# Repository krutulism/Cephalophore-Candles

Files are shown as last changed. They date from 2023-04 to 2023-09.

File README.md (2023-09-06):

# Ladder-LEDs
KiCAD 7 files for a chainable PCB of individually addressable LEDs.

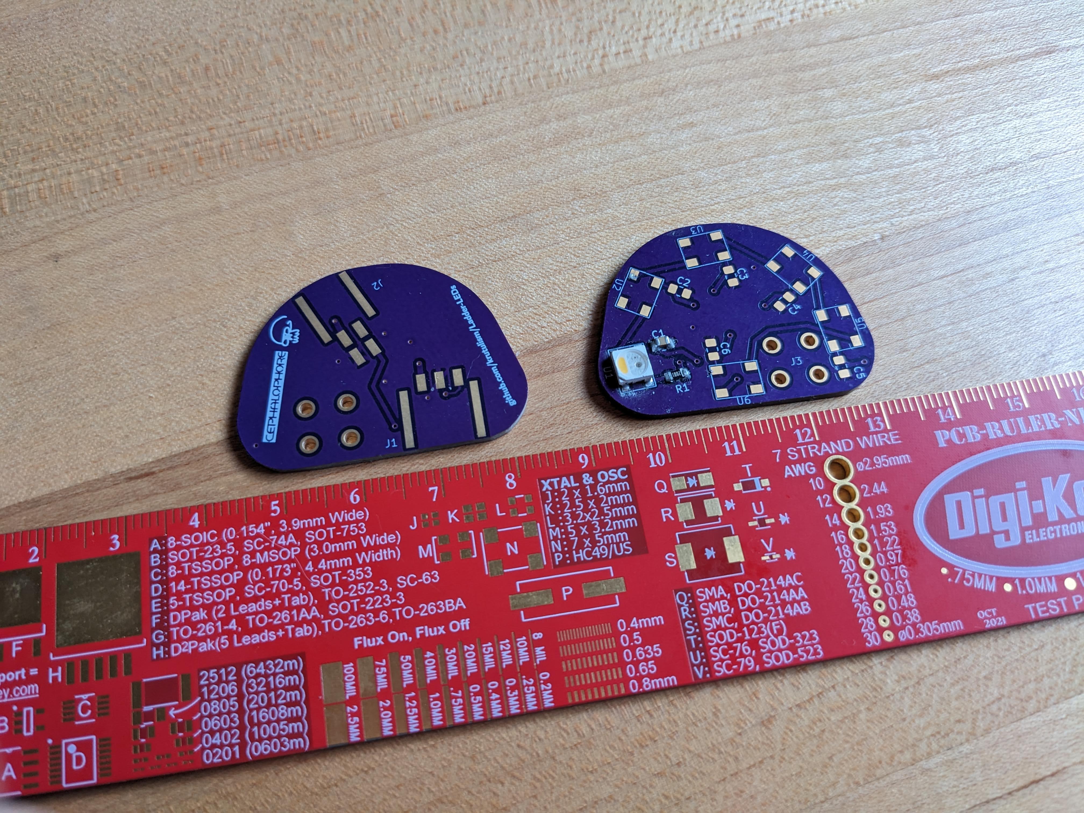
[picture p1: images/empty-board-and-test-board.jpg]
Empty board back and test board front

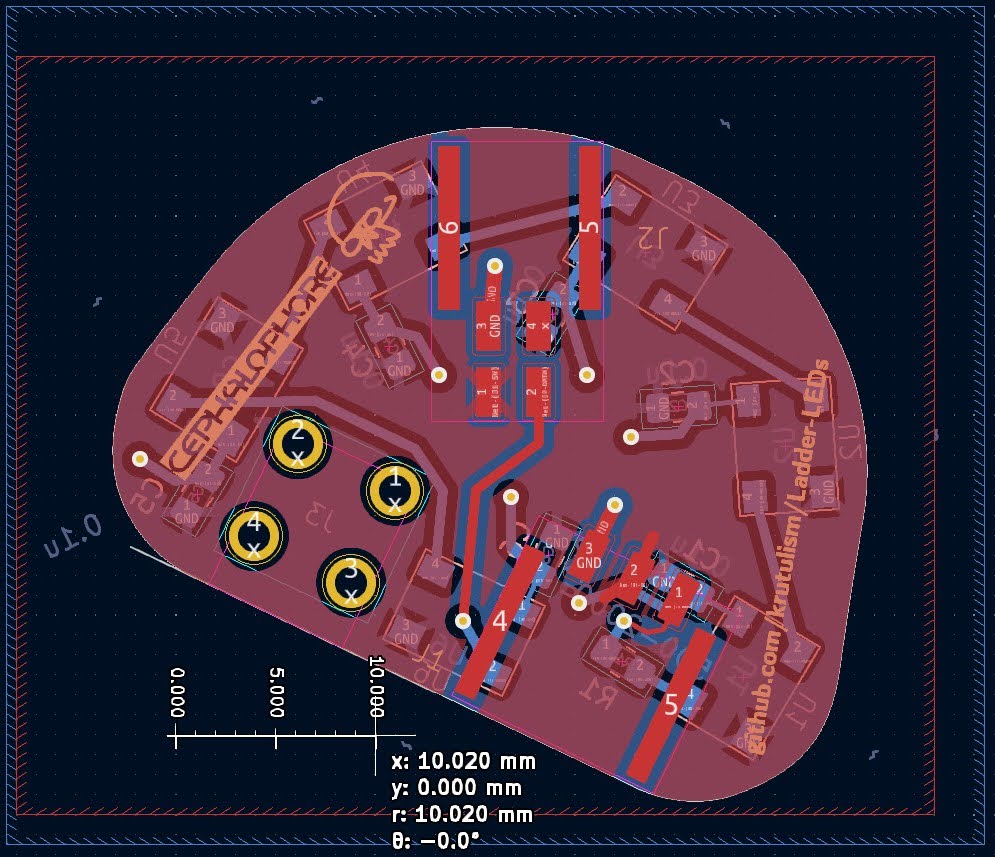
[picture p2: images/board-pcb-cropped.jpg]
PCB Layout from KiCAD


## Abstract
Strips of individually addressable LEDs are a popular and versatile gadget. Here I develop my own degree of craftsmanship beyond the adhesive strips they often come packaged on.

I used Molex connectors to chain together rigid fiberglass PCBs. The 'housing' that motivates the shape of the PCBs is the empty rungs of a salvaged aluminum extension ladder.

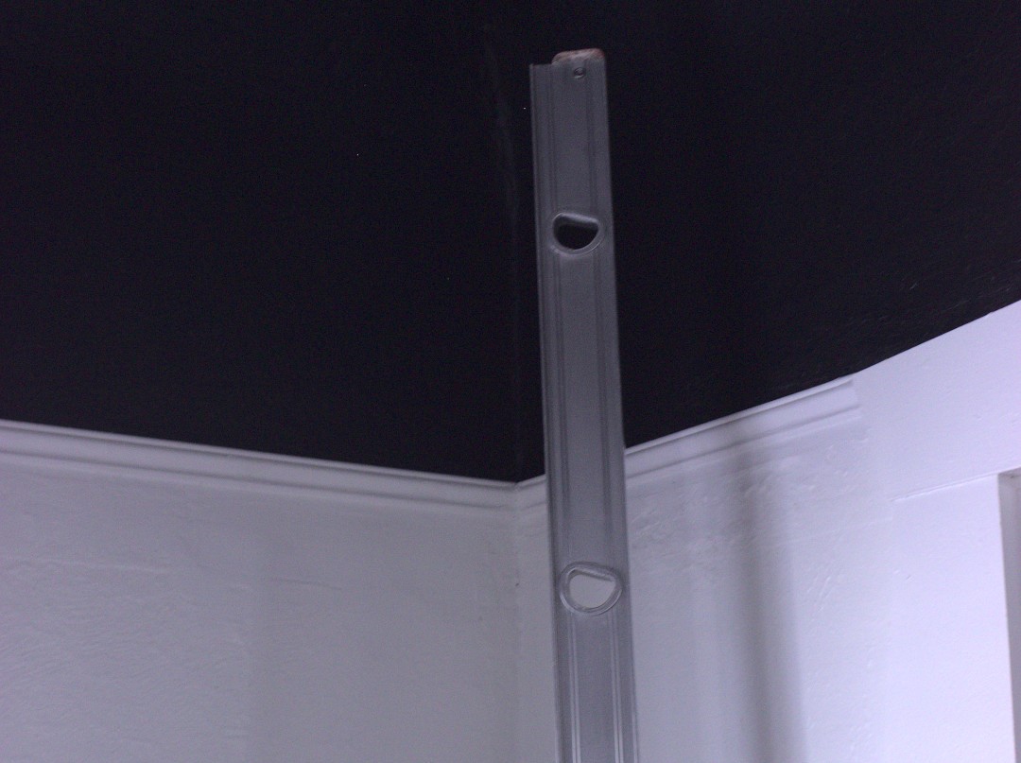
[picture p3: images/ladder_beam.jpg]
Scrapped aluminum ladder with D-shaped rungs


## Decision Tree
In each cut-off rung I will install a custom PCB designed in KiCAD.

The individually addressable LEDs I will use are the IN-PI55QATPRPGPBPW-40 RGBW shift register LEDs from Inolux.

The connector ecosystem that will allow me to chain these boards together are the Molex Nanofit system.

I will attempt to use a screw terminal block to mount the boards.

The prototype controller will be an Arduino Uno or Nano.

I will solder the surface mount components to the board by upgrading an IR reflow oven.

## First Demo
[Test program video (Google photos link)](https://photos.app.goo.gl/88sZqstjhHEQxjQ36)

## Instructions
To correct the paths to 3D models of custom library components: select a footprint in the PCB editor, edit its properties in the right click context menu or by pressing the E key, and enter the "3D Models" tab

CAD models I derived from datasheet drawings are included. CAD models I downloaded from the manufacturer can be downloaded from manufacturer websites.

## Questions
My Arduino firmware treats these LEDs as SK6812RGBW LEDs, a common hobbyist standard. However, here is a table of data transmission times for SK6812s accessed at Adafruit:
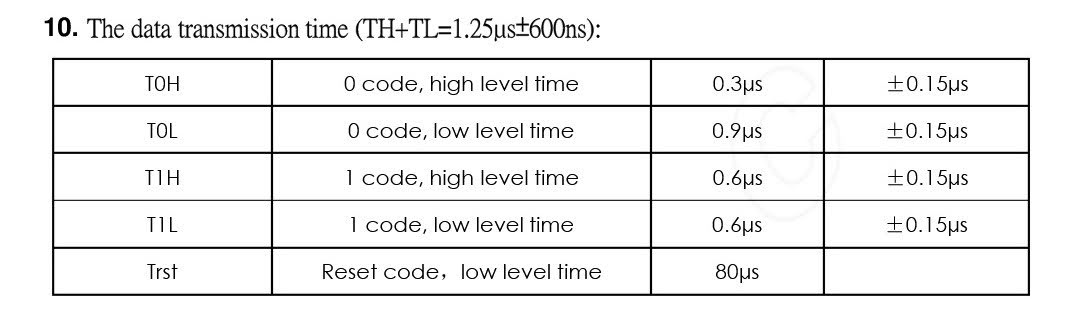
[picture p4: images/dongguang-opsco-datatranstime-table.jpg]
Data transmission times for SK6812


and here is the table for the Inolux IN-PI55QATPRPGPBPW-40 LEDs I used
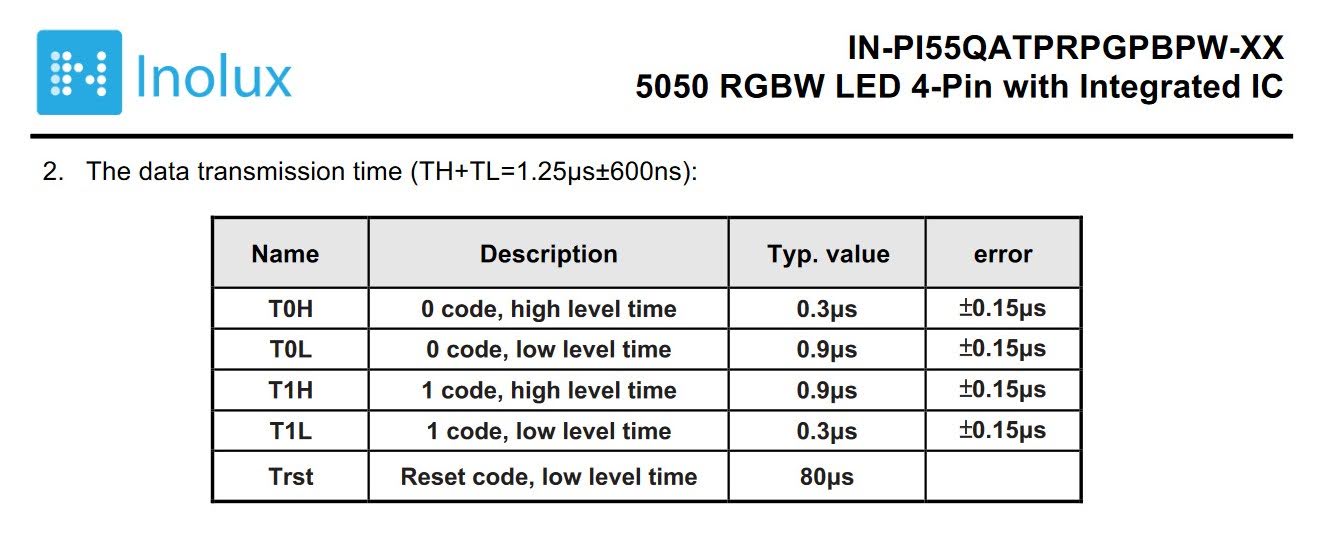
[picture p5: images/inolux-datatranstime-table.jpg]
Data transmission times for Inolux IN-PI...


In scrubbing through the source libraries for [Adafruit Neopixel](https://github.com/adafruit/Adafruit_NeoPixel), which is used in my demo, I did not find where these transmission times are encoded. This leaves me wondering where my elision will break down, whether after adding more LEDs to the chain, or under a greater frequency of intensity change commands. I will keep scrubbing the source code to understand, but suggestions are welcome.

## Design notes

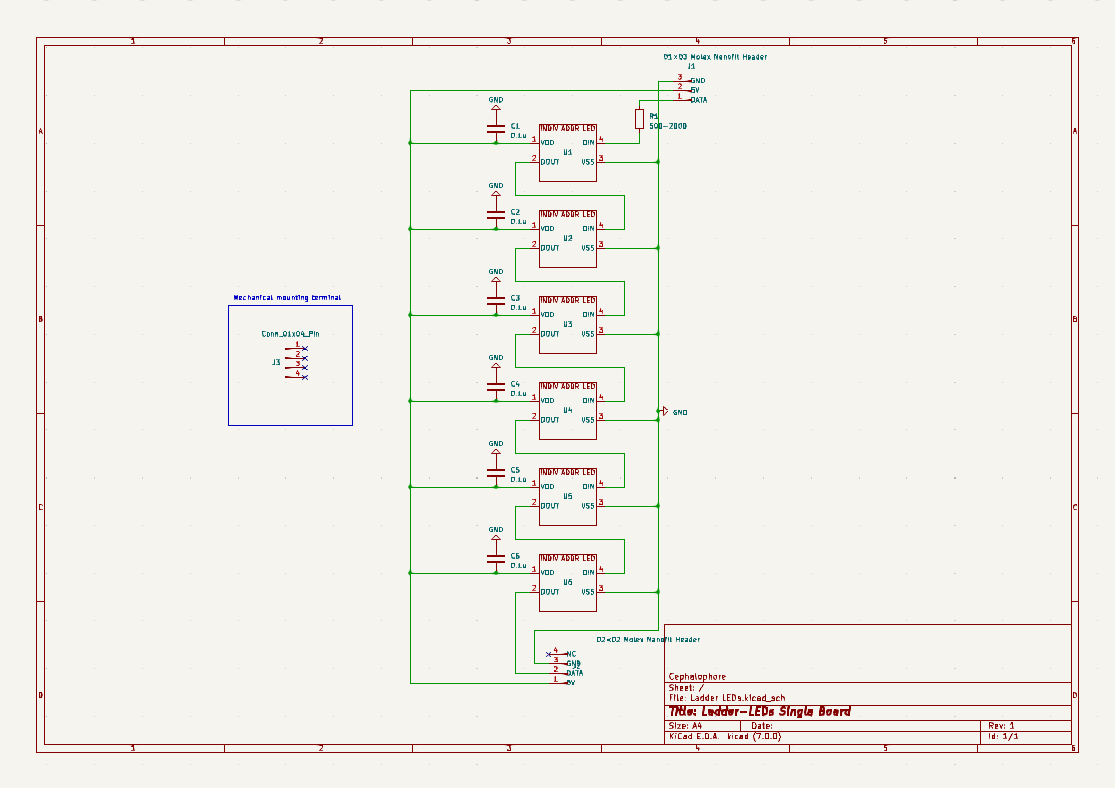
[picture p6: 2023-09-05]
images/KiCad_Schematic.png

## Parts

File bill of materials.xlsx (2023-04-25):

Index | Description |  | Color | Manufacturer | Manufacturer PN | Supplier | Approx price | Amount | URL
 | Nanofit receptacle 3-circuit | wire | Natural | Molex | 1053072203 (https://www.molex.com/molex/search/partSearch?query=1053072203&pQuery=) |  | $0.40 |  | https://www.digikey.com/en/products/detail/molex/1053072203/6164105?s=N4IgTCBcDaIIwAYCsBmBB2MYEpAXQF8g
 | Nanofit receptacle 4-circuit 2×2 | wire | Black | Molex | 1053081204 |  | $0.38 |  | https://www.digikey.com/en/products/detail/molex/1053081204/6131604?s=N4IgTCBcDaIIwAYCsBmBAOOYEBYQF0BfIA
 | Nanofit header 3-circuit |  |  | Molex | 1054302103 |  |  |  | https://www.digikey.com/en/products/detail/molex/1054302103/9959387?s=N4IgTCBcDaIIwAYCsAWAzAsi0gLoF8g
 | Nanofit header 4-circuit 2×2 |  |  | Molex | 1054051104 |  |  |  | https://www.newark.com/molex/105405-1104/conn-r-a-hdr-4pos-2row-2-5mm-smt/dp/26AK3878?st=1054051104
 | Nanofit terminals |  |  | Molex |  |  |  |  | https://www.molex.com/molex/search/partSearch?query=105300
 | Nanofit 3-position TPA retainer |  |  | Molex
 | Nanofit 2-position TPA retainer |  |  | Molex
 | Right angle 4-40 screw terminal | THT |  |  |  |  |  |  | https://www.digikey.com/en/products/detail/keystone-electronics/7773/4499350
 | Capacitor | SMD |  |  | 1276-1003-1-ND (https://www.digikey.com/en/products/detail/samsung-electro-mechanics/CL21B104KBCNNNC/3886661) |  |  |  | https://www.digikey.com/en/products/detail/samsung-electro-mechanics/CL21B104KBCNNNC/3886661
 | RGBW Indiv. Address. LED | SMD | Neutral white |  |  |  |  |  | https://www.digikey.com/en/products/detail/inolux/IN-PI55QATPRPGPBPW-40/9681240
 | Resistor
 | 4-40 screw

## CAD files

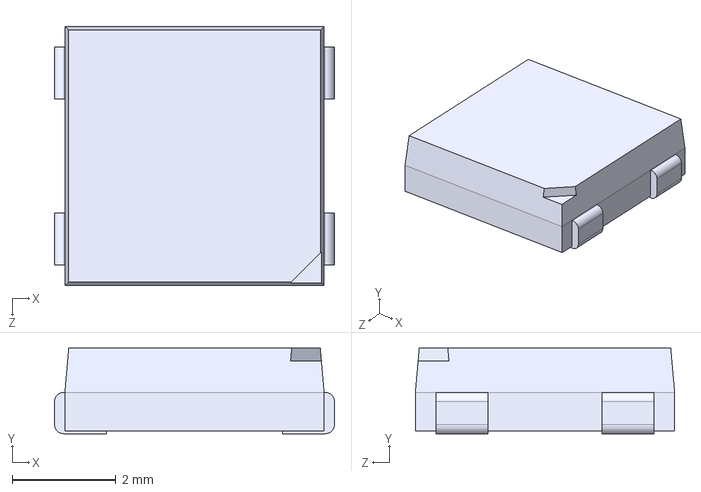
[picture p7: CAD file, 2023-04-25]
CAD models/IN-PI55QATPRPGPBPW-XX/IN-PI55QATPRPGPBPW-XX.STEP
5.40 x 1.65 x 5.00 mm

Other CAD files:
CAD models/IN-PI55QATPRPGPBPW-XX/IN-PI55QATPRPGPBPW-XX.SLDPRT

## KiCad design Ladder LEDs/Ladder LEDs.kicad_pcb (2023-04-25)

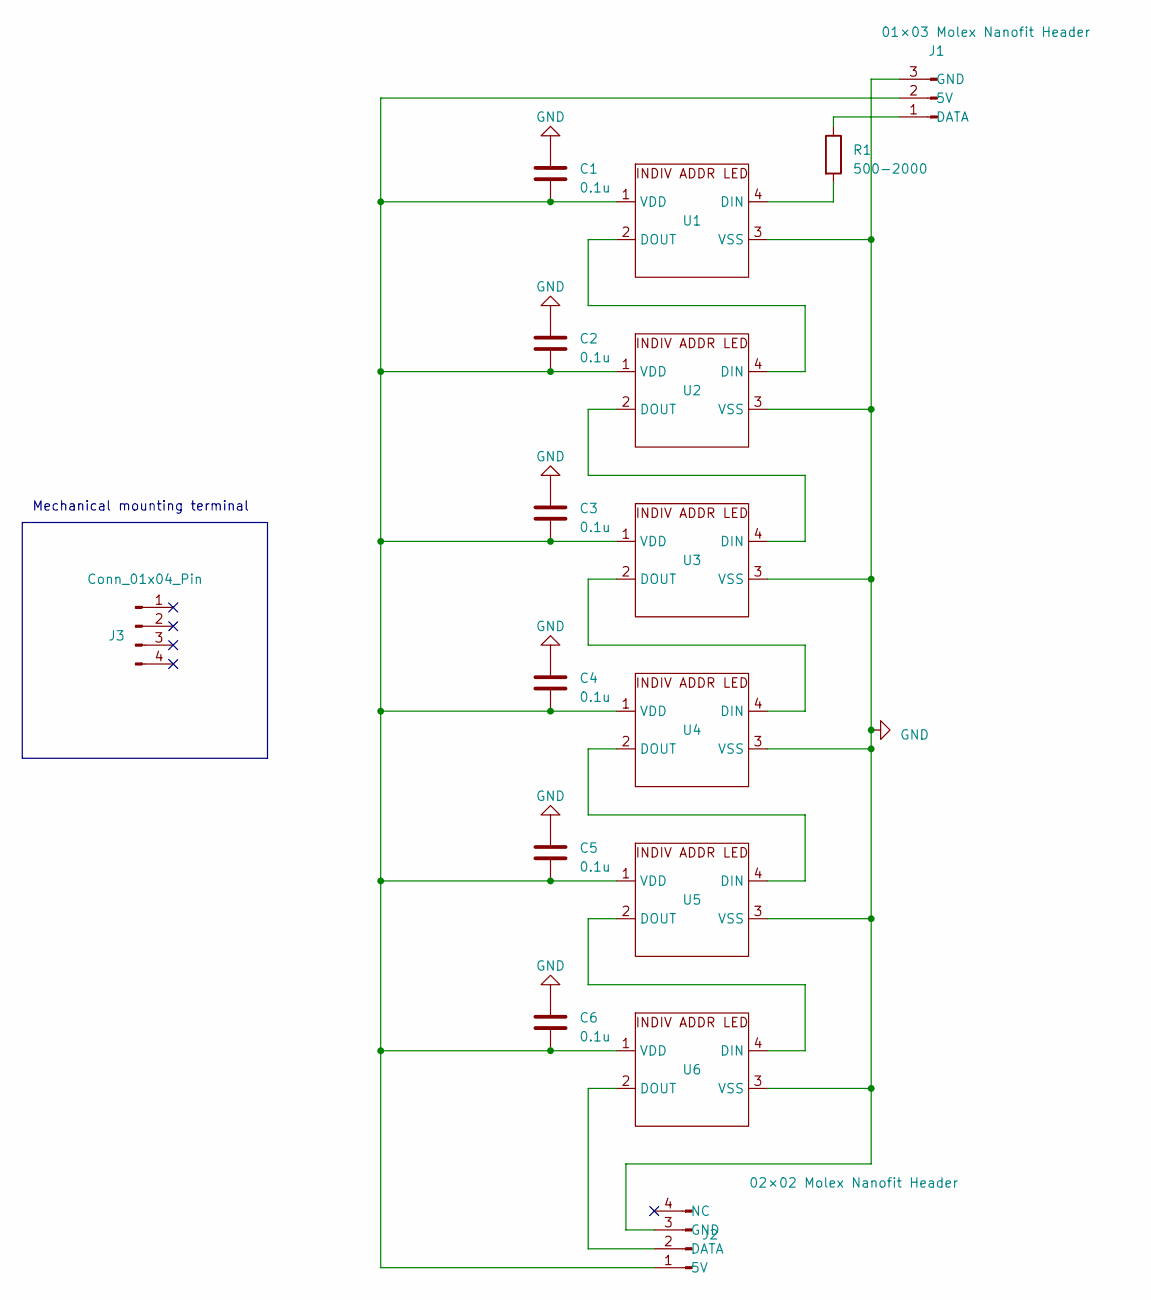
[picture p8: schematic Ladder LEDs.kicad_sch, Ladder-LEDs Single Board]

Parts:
C1, C2, C3, C4, C5, C6: 0.1u; C_0805_2012Metric_Pad1.18x1.45mm_HandSolder
J1: 01×03 Molex Nanofit Header; Molex 1054302103; MPN 1054302103
J2: 02×02 Molex Nanofit Header; Molex 105405-1104; MPN 1054051104
J3: Conn_01x04_Pin; 36-7773-ND; MPN 7773
R1: 500-2000; R_0805_2012Metric_Pad1.20x1.40mm_HandSolder
U1, U2, U3, U4, U5, U6: IN-PI55QATPRPGPBPW-XX

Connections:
GND: C1.1, C2.1, C3.1, C4.1, C5.1, C6.1, J1.3 (GND), J2.3 (GND), U1.3 (VSS), U2.3 (VSS), U3.3 (VSS), U4.3 (VSS), U5.3 (VSS), U6.3 (VSS)
unnamed: C1.2, C2.2, C3.2, C4.2, C5.2, C6.2, J1.2 (5V), J2.1 (5V), U1.1 (VDD), U2.1 (VDD), U3.1 (VDD), U4.1 (VDD), U5.1 (VDD), U6.1 (VDD)
unnamed: J1.1 (DATA), R1.1
unnamed: J2.2 (DATA), U6.2 (DOUT)
unnamed: R1.2, U1.4 (DIN)
unnamed: U1.2 (DOUT), U2.4 (DIN)
unnamed: U2.2 (DOUT), U3.4 (DIN)
unnamed: U3.2 (DOUT), U4.4 (DIN)
unnamed: U4.2 (DOUT), U5.4 (DIN)
unnamed: U5.2 (DOUT), U6.4 (DIN)

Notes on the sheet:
Mechanical mounting terminal

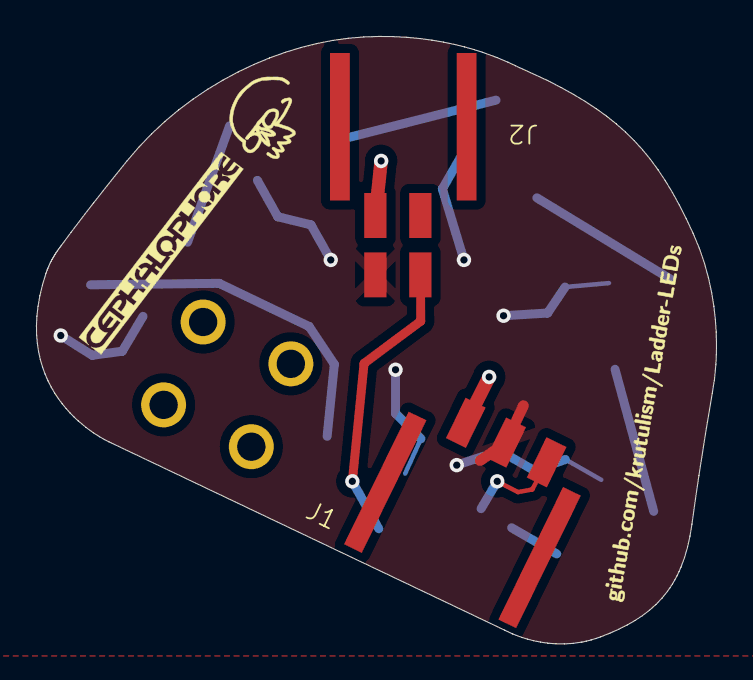
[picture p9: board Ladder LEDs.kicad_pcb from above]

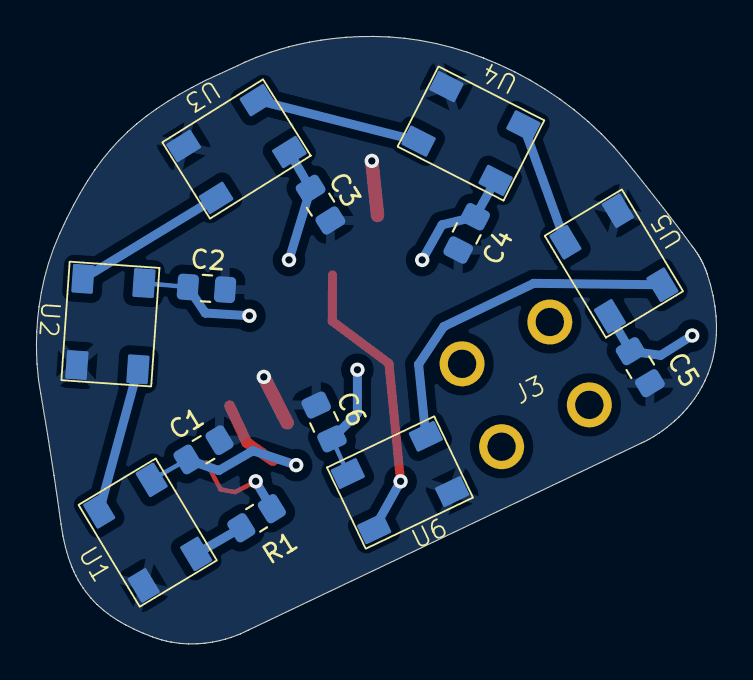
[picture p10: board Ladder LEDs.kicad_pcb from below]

Board: 2 copper layers, 37.8 x 33.7 mm, 16 parts (13 on the bottom side), 10 nets.

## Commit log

2023-03-21 Imported v1 KiCAD files
    [Ladder LEDs v1.kicad_pcb, Ladder LEDs v1.kicad_sch, bill of materials v1.xlsx]
2023-03-22 Created Gerber files for OSH Park
    [Ladder LEDs v1-B_Cu.gbr, Ladder LEDs v1-B_Mask.gbr, Ladder LEDs v1-B_Paste.gbr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]
2023-03-29 Placed Gerber files in folder
    [Ladder LEDs v1-B_Cu.gbr, Ladder LEDs v1-B_Mask.gbr, Ladder LEDs v1-B_Paste.gbr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]
2023-03-29 Renamed project, ignored backups
    [Ladder LEDs v1-B_Cu.gbr, Ladder LEDs v1-B_Mask.gbr, Ladder LEDs v1-B_Paste.gbr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]
2023-04-25 Trimmed BOM, added 3D models
    [1054051104.stp, 1054302103.stp, IN-PI55QATPRPGPBPW-XX.SLDPRT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]
2023-04-25 Troubleshooting gitignore
    [1054051104.stp, 1054302103.stp, keystone-PN7779.STEP]
